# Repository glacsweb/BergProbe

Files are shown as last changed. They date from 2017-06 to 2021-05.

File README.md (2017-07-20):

# BergProbe
Repository for schematics and PCB layouts for the 2017 BergProbes.

### BergProbe/
Contains layouts for the BergProbe schematic (control+power board)

### BergProbe-Adapter/
Contains layouts for a breakout board for GPS and Radio modules, with connector for connecting to BergProbe board.

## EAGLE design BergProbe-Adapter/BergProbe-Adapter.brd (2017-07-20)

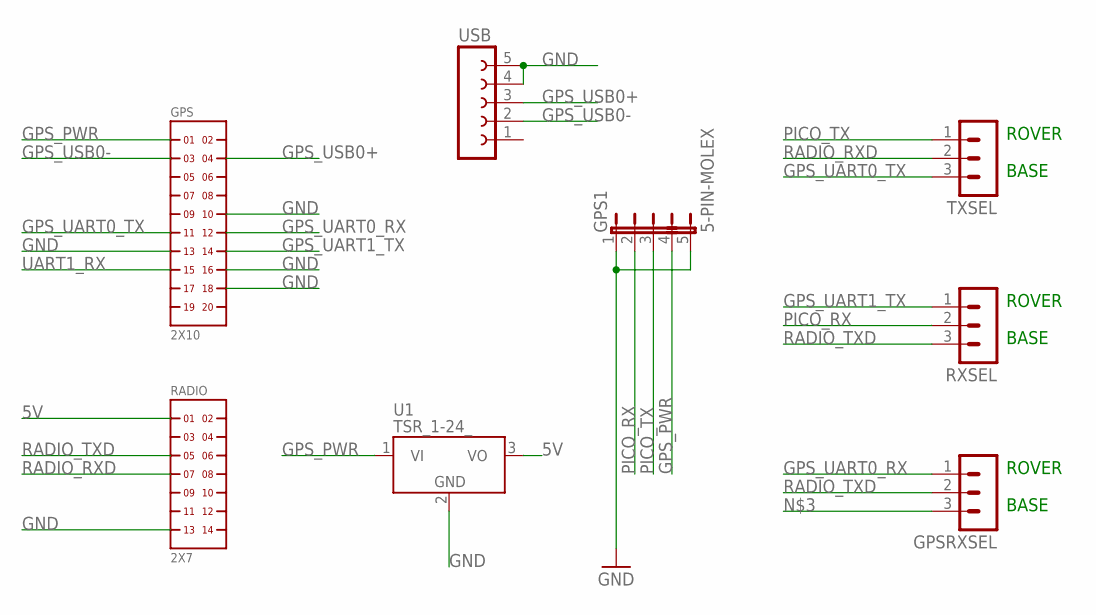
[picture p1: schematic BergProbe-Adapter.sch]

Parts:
GPS: 2X10
GPS1: 5-PIN-MOLEX; 5-MOLEX
GPSRXSEL: MA03-1
RADIO: 2X7
RXSEL: MA03-1
TXSEL: MA03-1
U1: TSR_1-24_; TSR-1
USB: FE05-1

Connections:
5V: RADIO.1, U1.3 (VO)
GND: GPS.10, GPS.13, GPS.16, GPS.18, GPS1.1, GPS1.5 (6), RADIO.13, U1.2 (GND), USB.4, USB.5
GPS_PWR: GPS.1, GPS1.4, U1.1 (VI)
GPS_UART0_RX: GPS.12, GPSRXSEL.1
GPS_UART0_TX: GPS.11, TXSEL.3
GPS_UART1_TX: GPS.14, RXSEL.1
GPS_USB0+: GPS.4, USB.3
GPS_USB0-: GPS.3, USB.2
PICO_RX: GPS1.2, RXSEL.2
PICO_TX: GPS1.3, TXSEL.1
RADIO_RXD: RADIO.7, TXSEL.2
RADIO_TXD: GPSRXSEL.2, RADIO.5, RXSEL.3
UART1_RX: GPS.15

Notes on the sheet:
ROVER
BASE

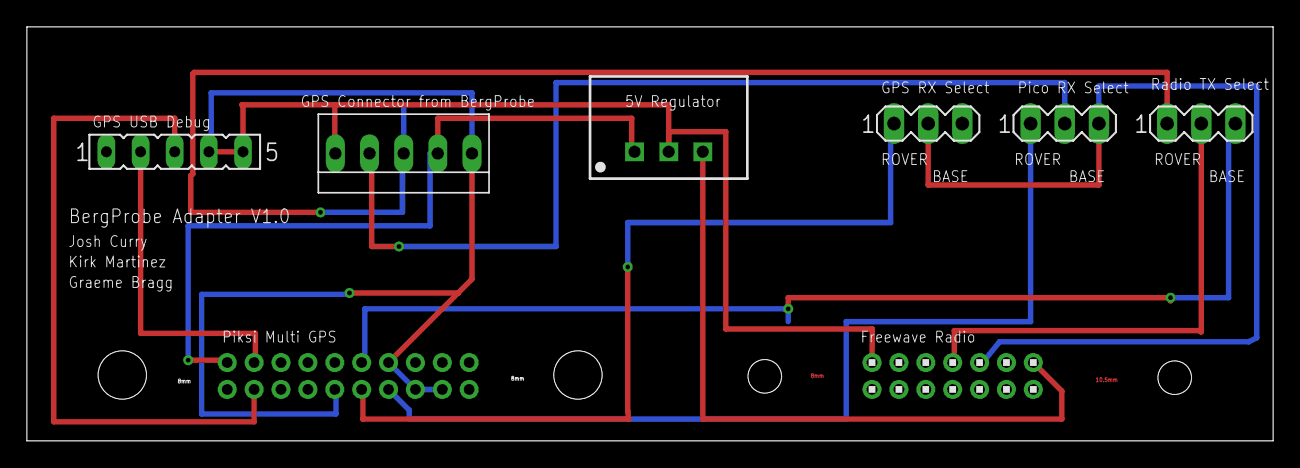
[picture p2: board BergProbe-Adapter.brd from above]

Board: 2 copper layers, 92.7 x 30.8 mm, 8 parts (1 on the bottom side), 12 nets.

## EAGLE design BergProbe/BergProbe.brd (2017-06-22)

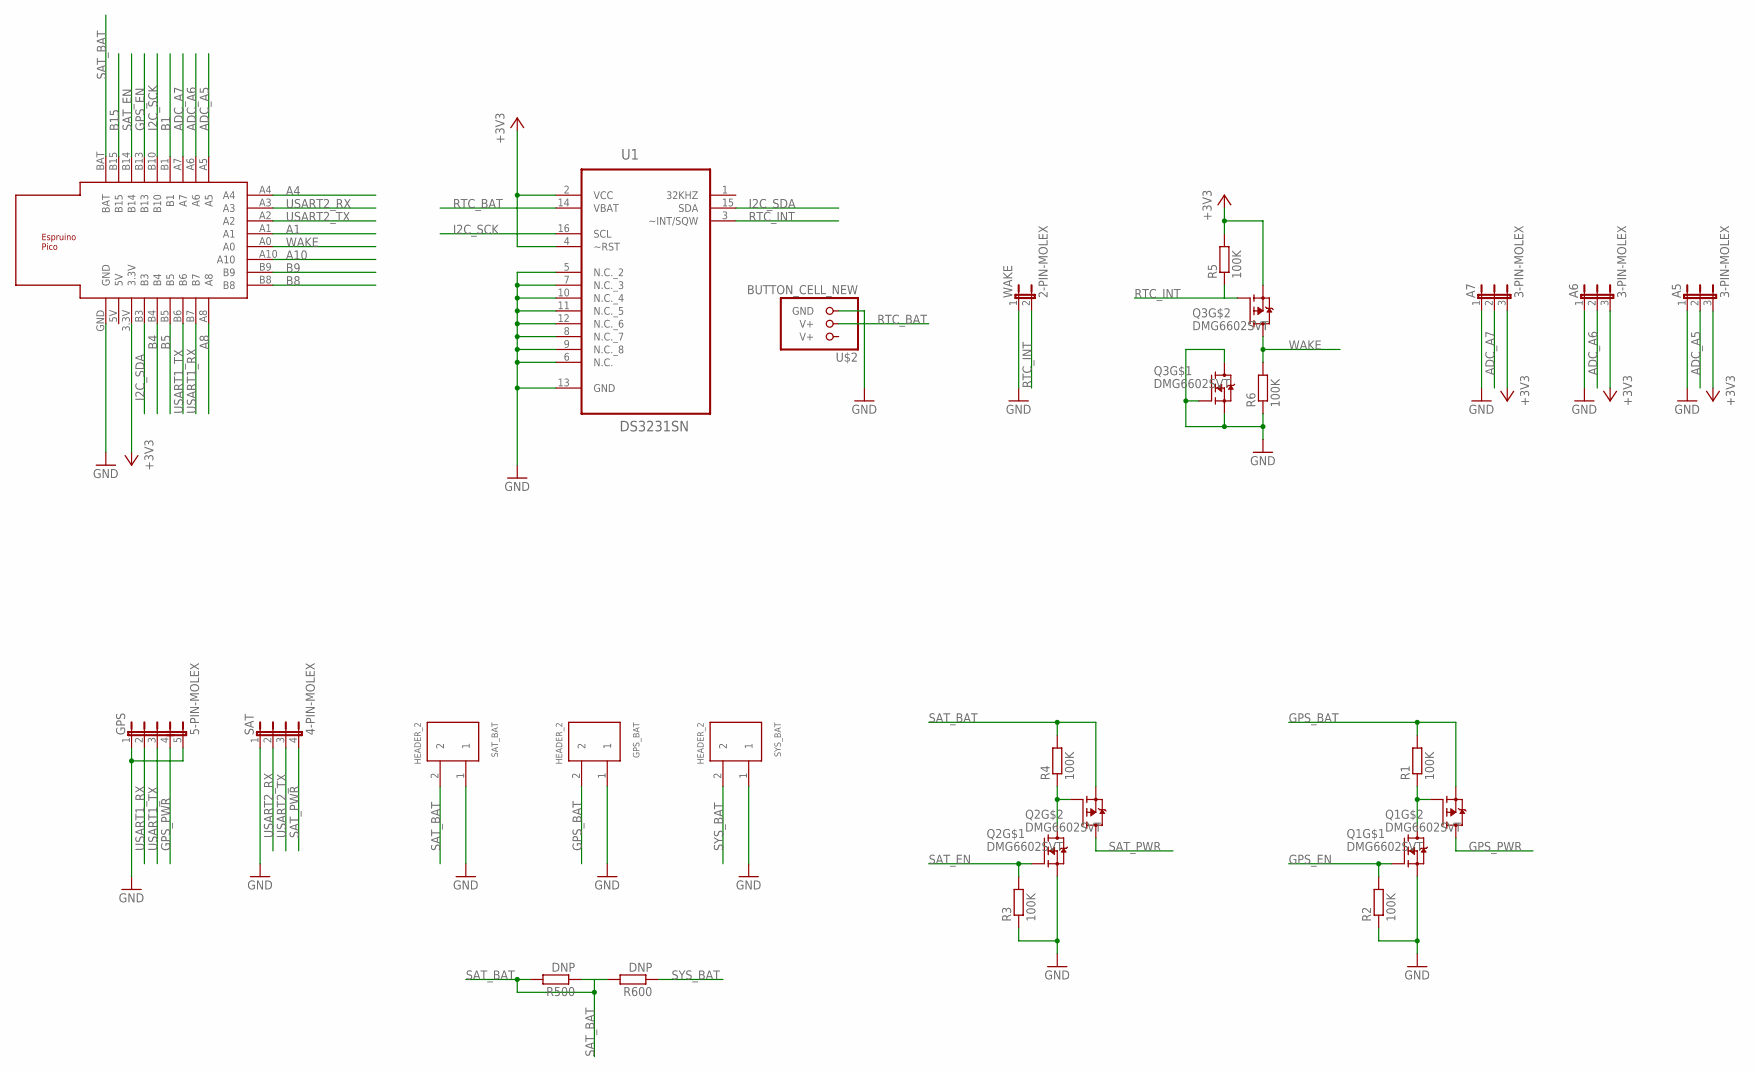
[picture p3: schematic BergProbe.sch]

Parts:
A5, A6, A7: 3-PIN-MOLEX; 3-MOLEX
GPS: 5-PIN-MOLEX; 5-MOLEX
GPS_BAT: HEADER_2; LUMBERG_CAGE_2
Q1, Q2, Q3: DMG6602SVT; TSOT26
R1, R2, R3, R4, R5, R6: 100K; R0805
R500, R600: DNP; R0805
SAT: 4-PIN-MOLEX; 4-MOLEX
SAT_BAT: HEADER_2; LUMBERG_CAGE_2
SYS_BAT: HEADER_2; LUMBERG_CAGE_2
U1: DS3231SN; SOIC127P1032X265-16N
U$1: ESPRUINO_PICO_SMDONLY
U$2: BUTTON_CELL_NEW; CR2016
WAKE: 2-PIN-MOLEX; 2-MOLEX

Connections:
+3V3: A5.3, A6.3, A7.3, Q3.P$2 (S), R5.2, U1.2 (VCC), U1.4 (~RST), U$1.3.3V
A1: U$1.A1
A4: U$1.A4
A8: U$1.A8
A10: U$1.A10
ADC_A5: A5.2, U$1.A5
ADC_A6: A6.2, U$1.A6
ADC_A7: A7.2, U$1.A7
B1: U$1.B1
B4: U$1.B4
B5: U$1.B5
B8: U$1.B8
B9: U$1.B9
B15: U$1.B15
GND: A5.1, A6.1, A7.1, GPS.1, GPS.5 (6), GPS_BAT.1, Q1.P$5 (S), Q2.P$5 (S), Q3.P$1 (G), Q3.P$5 (S), Q3.P$6 (D), R2.1, R3.1, R6.1, SAT.1, SAT_BAT.1, SYS_BAT.1, U1.5 (N.C._2), U1.6 (N.C.), U1.7 (N.C._3), U1.8 (N.C._7), U1.9 (N.C._8), U1.10 (N.C._4), U1.11 (N.C._5), U1.12 (N.C._6), U1.13 (GND), U$1.GND, U$2.GND, WAKE.1
GPS_BAT: GPS_BAT.2, Q1.P$2 (S), R1.2
GPS_EN: Q1.P$1 (G), R2.2, U$1.B13
GPS_PWR: GPS.4, Q1.P$4 (D)
I2C_SCK: U1.16 (SCL), U$1.B10
I2C_SDA: U1.15 (SDA), U$1.B3
unnamed: Q1.P$3 (G), Q1.P$6 (D), R1.1
unnamed: Q2.P$3 (G), Q2.P$6 (D), R4.1
RTC_BAT: U1.14 (VBAT), U$2.V+@2 (V+)
RTC_INT: Q3.P$3 (G), R5.1, U1.3 (~INT/SQW), WAKE.2
SAT_BAT: Q2.P$2 (S), R4.2, R500.1, R500.2, R600.2, SAT_BAT.2, U$1.BAT
SAT_EN: Q2.P$1 (G), R3.2, U$1.B14
SAT_PWR: Q2.P$4 (D), SAT.4
SYS_BAT: R600.1, SYS_BAT.2
USART1_RX: GPS.2, U$1.B7
USART1_TX: GPS.3, U$1.B6
USART2_RX: SAT.2, U$1.A3
USART2_TX: SAT.3, U$1.A2
WAKE: Q3.P$4 (D), R6.2, U$1.A0

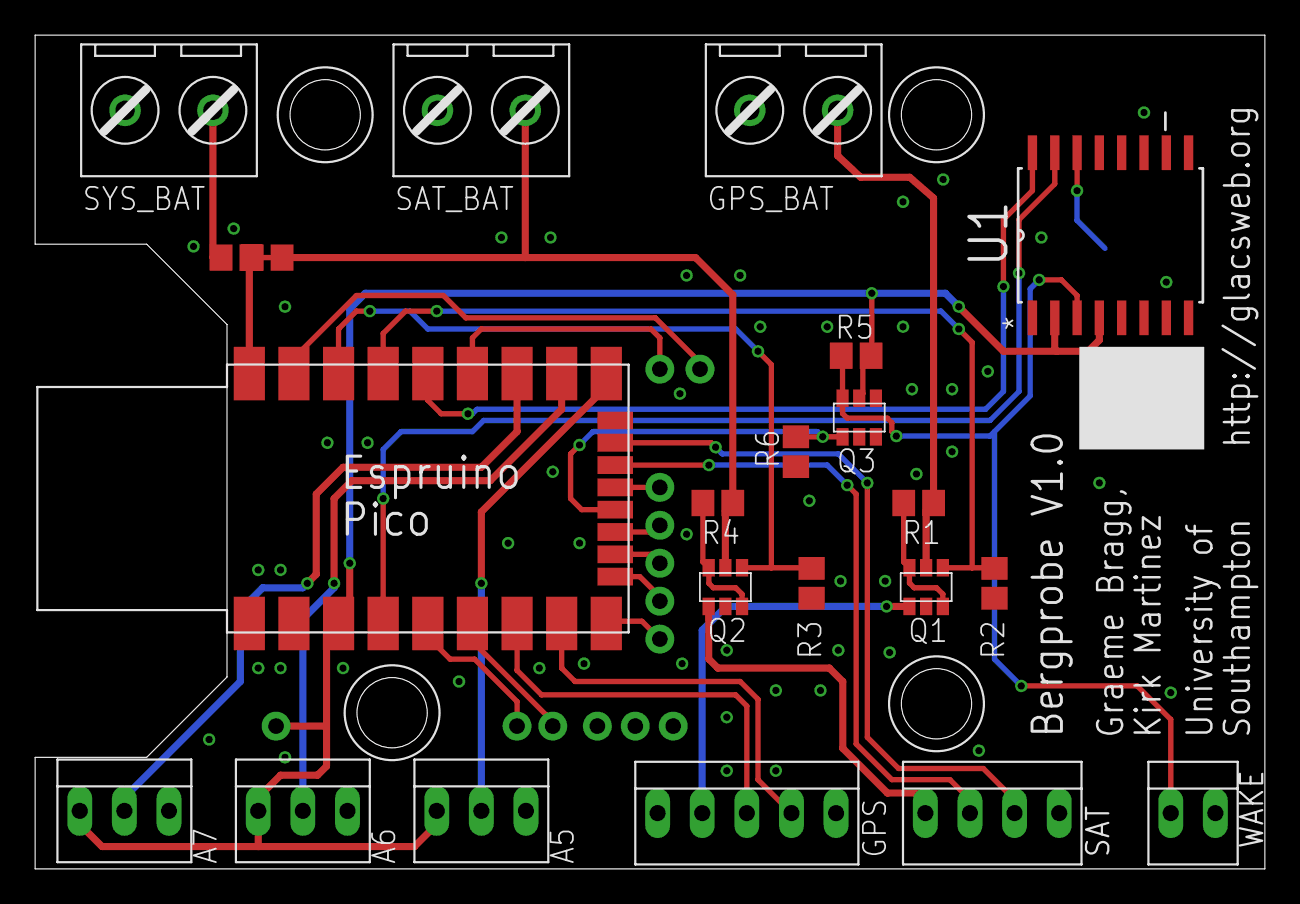
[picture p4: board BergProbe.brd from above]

Board: 2 copper layers, 70.0 x 47.5 mm, 23 parts (1 on the bottom side), 23 nets.

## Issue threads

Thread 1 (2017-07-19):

Pull ups on I2C missing

heliosfa, 2017-07-19:

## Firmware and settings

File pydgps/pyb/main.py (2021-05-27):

/* micropython ublox M9 based movement tracker
 * for the glacsweb.org project
 * Authors: Emily James 2020, University of Southampton

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
    see <https://www.gnu.org/licenses/> for the GNU General Public License
*/
from random import randint
from math import ceil
import pyb
import json
# from machine import WDT
from pyb import UART

import LCD
import Log
from Message import *
from Formats import *
import os

stat = None
pack_buf = []
nextpack = None
pl_length_rem = 0  # will be assigned when first packet found
until_len = None  # will be assigned when first packet found
calibrated = False

DEVICE_ID = 0
GPS_UART_PORT = 6
GPS_BAUDRATE = 38400
GPS_TIMEOUT = 1001 # ms
GPS_BUF_SIZ = 512 # bytes

IS_BASE_STATION = False
SVIN_DUR = 600 # 5 min
SVIN_ACC = 10000 # 10m
RADIO_UART_PORT = 3
RADIO_BAUDRATE = 38400
RADIO_TIMEOUT = 1000
RADIO_BUF_SIZ = 1024

# gpsIn = UART(6, 38400)
# gpsIn.init(38400, bits=8, parity=None, stop=1, read_buf_len=512,
#            timeout=1001)  # timeout should overlap epochs -> 1s atm

# wdt = WDT(timeout=10000)
TIME_CONF_LIMIT = 500  # number of readings before time-resync
timeConfidence = 0  # update time on 0 ==> on reset or start time is set

msg_buf = {}
msg_count = 0

monitoring = False

## MUST BE SET FROM 0 -> NO_MSGS ##
# determines location in each epoch list - don't change!
# LOC_CODE = 0
# STAT_CODE = 1
# SATINF_CODE = 2
# TIMEUTC_CODE = 3
# SVIN_CODE = 4
# set to -2 to disable (since -1 is used for no message, could cause accidental matches)
LOC_CODE = -2
STAT_CODE = -2
SATINF_CODE = -2
SVIN_CODE = -2
TIMEUTC_ENABLED = True

LOG_RAW = False
LOG_MEDIAN = True
LOG_BEST = True
UPDATE_DELAY = 1 # works best if harmonises with 1000ms i.e. 250, 500, 125, etc.

NO_READINGS = 25  # number of positions used in one reading
NO_MSGS = 3  # ROVER: number of messages per epoch (HPECEF, SAT, STATUS) = 3 --> NOTE that TIMUTC is used then discarded once time is updated
MAX_READING_ATTEMPTS = 100 # prevents livelock in case no message triples are valid
MAX_PACK_BUF = 25
CALIBRATION_TTL = 1000 # maximum number of bytes that will be read in one calibration before timeout
MAX_CALIBRATE_FAILURES = 50 # number of UART timeouts until calibration attepts stopped
# NO_MSGS = 5 # BASE STATION: number of messages per epoch (HPECEF, SAT, STATUS, TIMEUTC, SVIN) = 5
# MSG_PERIOD = 8 * 60 * 60  # (in seconds) every eight hours - min. 1 minute (50 readings taken with a delay of 1s
# between them)
MSG_PERIOD = 120  # two-minute debug mode
# MSG_PERIOD = 28800  # normal default
if MSG_PERIOD < 60:
    MSG_PERIOD = 60
# MSG_PERIOD *= 1000  # convert from s to ms

MSG_START_TIME = 12  # defines the first hour in which the readings will take place. no sub-hour accuracy as intended
                     # use is for < 10 readings per day
TRANSMIT_AFTER = 3 # 3 readings before transmit
MAX_TRANSMIT_ATTEMPTS = 3 # defines how many times a file will be transmitted before deletion

def loadBaseStationParams(data):
    global IS_BASE_STATION, SVIN_ACC, SVIN_DUR
    IS_BASE_STATION = True
    if 'svin_acc' in data:
        SVIN_ACC = data['svin_acc']
    if 'svin_dur' in data:
        SVIN_DUR = data['svin_dur']

def loadLogParams(data):
    global LOC_CODE, STAT_CODE, SATINF_CODE, TIMEUTC_ENABLED, SVIN_CODE, NO_MSGS, NO_READINGS, MAX_READING_ATTEMPTS, LOG_RAW, LOG_MEDIAN, LOG_BEST, MAX_PACK_BUF
    if 'no_readings' in data:
        NO_READINGS = data['no_readings']
    if 'max_reading_attempts' in data:
        MAX_READING_ATTEMPTS = data['max_reading_attempts']
    if 'max_pack_buf' in data:
        MAX_PACK_BUF = data['max_pack_buf']
    if 'log_raw' in data:
        LOG_RAW = data['log_raw']
    if 'log_median' in data:
        LOG_MEDIAN = data['log_median']
    if 'log_best' in data:
        LOG_BEST = data['log_best']
    if 'msgs_enabled' in data:
        msgs = data['msgs_enabled']
        c = 0
        for msg_type in msgs:
            if msgs[msg_type]:
                if msg_type == 'HPECEF':
                    LOC_CODE = c
                elif msg_type == 'STATUS':
                    STAT_CODE = c
                elif msg_type == 'SAT_INFO':
                    SATINF_CODE = c
                elif msg_type == 'TIMEUTC':
                    TIMEUTC_ENABLED = True
                    c -= 1
                elif msg_type == 'SVIN':
                    print("svin enabled")
                    SVIN_CODE = c
                    c -= 1
                c += 1
                print(LOC_CODE, STAT_CODE, SATINF_CODE, SVIN_CODE, c)
        if SVIN_CODE >= 0:
            SVIN_CODE = c

        NO_MSGS = c


def loadTimeParams(data):
    global MSG_PERIOD, MSG_START_TIME, TIME_CONF_LIMIT, UPDATE_DELAY, TRANSMIT_AFTER, MAX_TRANSMIT_ATTEMPTS
    if 'log_period_s' in data:
        MSG_PERIOD = data['log_period_s']
    if 'log_start' in data:
        MSG_START_TIME = data['log_start']
    if 'update_rtc_time' in data:
        TIME_CONF_LIMIT = data['update_rtc_time']
    if 'update_delay' in data:
        UPDATE_DELAY = data['update_delay']
    if 'transmit_after' in data:
        TRANSMIT_AFTER = data['transmit_after']
    if 'transmit_attempts' in data:
        MAX_TRANSMIT_ATTEMPTS = data['transmit_attempts']

def loadUARTParams(data):
    global GPS_UART_PORT, GPS_BAUDRATE, GPS_TIMEOUT, CALIBRATION_TTL, GPS_BUF_SIZ, gpsIn, DEVICE_ID, \
        MAX_CALIBRATE_FAILURES, RADIO_UART_PORT, RADIO_BAUDRATE, RADIO_TIMEOUT, RADIO_BUF_SIZ
    if 'device_id' in data:
        DEVICE_ID = data['device_id']
    if 'gps_uart' in data:
        GPS_UART_PORT = data['gps_uart']
    if 'gps_baudrate' in data:
        GPS_BAUDRATE = data['gps_baudrate']
    if 'gps_timeout' in data:
        GPS_TIMEOUT = data['gps_timeout']
    if 'gps_buffer_size' in data:
        GPS_BUF_SIZ = data['gps_buffer_size']
    if 'calibration_ttl' in data:
        CALIBRATION_TTL = data['calibration_ttl']
    if 'max_calibration_fail' in data:
        CALIBRATION_TTL = data['max_calibration_fail']
    if 'radio_uart' in data:
        RADIO_UART_PORT = data['radio_uart']
    if 'radio_baudrate' in data:
        RADIO_BAUDRATE = data['radio_baudrate']
    if 'radio_timeout' in data:
        RADIO_TIMEOUT = data['radio_timeout']
    if 'radio_buffer_size' in data:
        RADIO_BUF_SIZ = data['radio_buffer_size']

def getParamsFromConfig():
    try:
        with open("config.json") as f:
            data = json.load(f)
        # print(data)
        baseStation = 'base_station' in data and data['base_station']
        if baseStation:
            loadBaseStationParams(data)
        if 'lcd_start_on' in data and data['lcd_start_on']:
            LCD.powered = 1
        else:
            LCD.powered = 0

        loadLogParams(data)
        loadTimeParams(data)
        loadUARTParams(data)
    except Exception as e:
        print("Error {0}, using default parameters".format(e))


def calibrate():
    global CALIBRATION_TTL
    print("Calibrating...", end=" ")
    start_bit_one = False
    start_bit_two = False
    ttl = CALIBRATION_TTL
    remaining_failures = MAX_CALIBRATE_FAILURES
    while not (start_bit_one and start_bit_two) and ttl > 0 and remaining_failures > 0:
        curr = gpsIn.read(1)
        ttl -= 1
        if curr == b'\xb5':
            start_bit_one = True
        elif curr == b'\x62':
            start_bit_two = True
        elif curr is None:
            # uart timeout
            remaining_failures -= 1
        else:
            start_bit_one = False
            start_bit_two = False

    if ttl > 0 and remaining_failures > 0:
        print("Calibration Finished")
    else:
        print("Calibration timed out")
    return ttl > 0 and remaining_failures > 0

def readBytes():
    global nextpack, pack_buf, calibrated, gpsIn
    if gpsIn is None or len(pack_buf) > MAX_PACK_BUF:
        return False
    print("Reading...", end="")
    calibrated = gpsIn.read(2) == b'\xb5\x62'
    if not calibrated:
        calibrated = calibrate()
        Log.CalibrateEvent().writeLog()
    if not calibrated:
        Log.CalibrationTimeoutEvent().writeLog()
        return False
    # print(calibrated)
    nextpack = bytearray(b'\xb5\x62')
    class_id = gpsIn.read(2)
    pack_len_bytes = gpsIn.read(2)
    pack_len = U2(pack_len_bytes)
    # print(pack_len_bytes,pack_len, "bytes long")

    if pack_len > 100 and class_id != bytearray(b'\x01\x35'):
        Log.UnacceptableLengthError(pack_len_bytes).writeLog()
        print(class_id)
        print("BAD LENGTH", pack_len)
        return False
    elif class_id == bytearray(b'\x01\x35'):
        print("Sat message, length capped...", end="")
        Log.LengthForceError(b'\x01', b'\x35', pack_len_bytes, u2toBytes(8)).writeLog()
        pack_len = 8
        pack_len_bytes = u2toBytes(pack_len)
    payload = gpsIn.read(pack_len)
    crc = gpsIn.read(2)
    if crc is None:
        crc = b'\x00\x00'
    # print(crc,"crc")
    try:
        nextpack.extend(class_id)  # append class and ID to byte
        nextpack.extend(pack_len_bytes)
        nextpack.extend(payload)
        nextpack.extend(crc)
        pack_buf.append(nextpack)
    except Exception as e:
        Log.UnknownError("Reading bytes from UART").writeLog()
        print(e)
        print("Error:")
        print(class_id)
        print(pack_len_bytes)
        print(payload)
        print(crc)
        print("End error")
        # log error?
        return False
    nextpack = None
    print("Finished.")
    return True


# 0 -> High-precision ECEF data
# 1 -> GPS Status (ttff, fix status, etc.)
# 2 -> Satellite information (notably the number of satellites used)
# 3 -> Survey-in data (base station)
def getMessageFromBuffer():
    global pack_buf, msg_buf, LOC_CODE, STAT_CODE, SATINF_CODE, NO_MSGS, TIMEUTC_ENABLED, fixOK, dgpsUsed
    if len(pack_buf) == 0:
        return None, -1
    print(len(pack_buf))
    byte_stream = pack_buf[0]
    del pack_buf[0]
    print(byte_stream)
    msg = None
    try:
        msg = binaryParseUBXMessage(byte_stream)
    except:
        Log.UnknownError("when parsing ubx message from bytestream")

    if msg is None:
        return None, -1

    tow = msg.getTOW()
    # print(len(msg_buf), "messages in buffer")
    if tow not in msg_buf:
        msg_buf[tow] = [None] * NO_MSGS
    code = -1
    if isinstance(msg, HPECEF) and LOC_CODE >= 0:
        code = LOC_CODE
    elif isinstance(msg, Status) and STAT_CODE >= 0:
        code = STAT_CODE
        fixOK = msg.gpsFixOK
        dgpsUsed = msg.diffSol
    elif isinstance(msg, SatInfo) and SATINF_CODE >= 0:
        code = SATINF_CODE
    elif isinstance(msg, TimeUTC) and TIMEUTC_ENABLED:
        updateTime(msg)
    # SVIN should only come in on base station, leaving code here for ease of copying, could also make code more
    # deployable by copying gps-read code?
    elif isinstance(msg, SVIN) and SVIN_CODE >= 0:
        return msg, SVIN_CODE
    else:
        code = -1

    if code != -1:  # just in case msg is not being used -> TIMEUTC? maybe another message has been enabled by accident i.e. LLH
        msg_buf[tow][code] = msg
    updateLEDs()  # update LEDs as readings taken - shows if fix dies during read
    return msg, code


reading = False

# tells us if the last epoch was corrupted by:
# - not enough messages read from gps
# - some messages invalid from last epoch
def invalidEpoch(epoch_msgs):
    global NO_MSGS, STAT_CODE, LOC_CODE
    return any(map(lambda r: r is None, epoch_msgs)) or len(epoch_msgs) < NO_MSGS or not epoch_msgs[
        STAT_CODE].gpsFixOK or epoch_msgs[LOC_CODE].invalidFix


def getReadings(i=0):
    global msg_buf, msg_count, NO_READINGS, STAT_CODE, timeConfidence, MSG_PERIOD, reading, fixOK, dgpsUsed
    # shoudln't read twice at same time, or if nothing to log don't bother
    if reading or not (LOG_RAW or LOG_BEST or LOG_MEDIAN):
        print("Duplicate call?")
        return
    LCD.reading = True
    reading = True
    LCD.makeLCDBusy("getReadings")
    msg_buf = {}
    curepoch = 0
    lastepoch = 0
    chosen_msgs = []
    ttl = MAX_READING_ATTEMPTS # time to live, prevents livelock
    epochs = 0
    while epochs < (NO_READINGS + 1) and ttl > 0:
        bytesavailable = readBytes()
        print(epochs)
        if not bytesavailable:
            ttl -= 1
            # add delay to try to dislodge timeout / get more data in buffer
            pyb.delay(100)
            continue # restart iteration with hopefully more bytes in buffer - ttl should stop if many attempts taken
        msg, id = getMessageFromBuffer()
        print(msg, id)
        if msg is None:
            pyb.delay(10)
            continue
        curepoch = msg.getTOW()

        if curepoch != lastepoch and lastepoch != 0:
            print("------ ### ------")
            # if any messages are missing from last epoch, delete data from that epoch as unreliable (incomplete metadata)
            lastepoch_msgs = msg_buf[lastepoch]
            if invalidEpoch(lastepoch_msgs):
                msg_count -= sum(map(lambda r: r is not None, lastepoch_msgs))
                print("Some messages none on turn of next epoch, deleting epoch...")
                print(lastepoch_msgs)
                del msg_buf[lastepoch]
                ttl -= 1
                lastepoch = curepoch # might not work? needs testing
                continue # skip count increment
            elif LOG_RAW:
                # safe to log as raw data
                Log.ECEFLog(lastepoch_msgs[LOC_CODE], b'\xF1', lastepoch_msgs[SATINF_CODE]).writeLog()
                Log.LocationEvent(b'\x11').writeLog()  # write event log for location write
            epochs += 1
        # print(msg, id, msg_count)
        lastepoch = curepoch
        # original code for detecting location invalid -> moved to last epoch calculation
        # invalidFix = id == STAT_CODE and not msg.gpsFixOK or id == LOC_CODE and msg.invalidFix
        # if invalidFix:
        #     msg_count -= id
        #     del msg_buf[msg.iTOW]
        #     print("Invalid fix, deleting msg", msg_buf, msg_count, id == STAT_CODE and not msg.gpsFixOK, id == LOC_CODE and msg.invalidFix)
        #     Log.UnknownError("Invalid location deleted from buffer").writeLog()
        # else:

    # 0 msgs will only happen if timeout
    if len(msg_buf) > 0:
        del msg_buf[curepoch] # trim last epoch from buffer
    timeConfidence -= 1

    # clock will drift as time continues, update time when this reaches 0 (see TIME_CONF_LIMIT for readings before
    # reset)
    if LOG_MEDIAN and len(msg_buf) > 0:
        # print(msg_buf, msg_count)
        type_code = b'\x12'
        chosen_msgs.append((type_code, getMedianMsg(msg_buf)))

    if LOG_BEST and len(msg_buf) > 0:
        # take message with smallest pAcc --> most accurate of the readings
        type_code = b'\x13'
        chosen_msgs.append((type_code, getBestAcc(msg_buf)))

    if len(chosen_msgs) > 0:
        print(chosen_msgs)
        for t, m in chosen_msgs:
            # print(t, m)
            location = m[LOC_CODE]
            sats = m[SATINF_CODE]
            Log.ECEFLog(location, t, sats).writeLog()
            Log.LocationEvent(t).writeLog() # write event log for location write

    if not IS_BASE_STATION:
        transmitLogs()

    updateLCD()
    msg_buf = {}
    msg_count = 0
    LCD.makeLCDFree()
    reading = False
    LCD.reading = False
    print("\nREADINGS DONE\n")
    if LCD.powered == 0:
        pyb.stop() # put board into low-power mode until ext. interrupt

def forceReading():
    global clock
    print("\n\nForcing reading\n\n")
    clock.wakeup(None)
    getReadings()
    if not IS_BASE_STATION:
        clock.wakeup(10000, initialTimer)


def updateTime(timeMsg):
    global clock, timeConfidence, TIME_CONF_LIMIT
    if type(timeMsg) is not TimeUTC or not timeMsg.validTime() or timeConfidence > 0:
        print("No clock update: ", timeConfidence)
        timeConfidence -= 1
        return
    print("!!! Updating clock !!!")
    LCD.makeLCDBusy("Time update")
    Log.TimeUpdateEvent().writeLog()
    timeConfidence = TIME_CONF_LIMIT
    # assume Monday as gps doesn't give this data hence weekday=0
    LCD.makeLCDFree()
    clock.datetime((timeMsg.getYear(), timeMsg.getMonth(), timeMsg.getDay(), 1,
                    timeMsg.getHour(), timeMsg.getMinute(), timeMsg.getSeconds(), timeMsg.getNano()))


t_attempts = 1
# 300 readings - for loop?
# long timeout - .5s to keep in 1s epoch?
#

# RTC.wakeup(timeout, callback)
# can be used to do frequent events (callback might be typed badly idk)
# means we can wakeup from pyb.stop() (500uA) and immediately call a few iterations of main()

# allow for further implementation of LR comms - UART?
def transmitLogs():
    global TRANSMIT_AFTER, MAX_TRANSMIT_ATTEMPTS, t_attempts, dgpsUsed
    # don't run if don't want to transmit for some reason
    print("Might be transmitting..?",str(t_attempts),dgpsUsed)
    LCD.makeLCDBusy("transmitLogs")
    # don't transmit if configured not to (base station?) or if there is no radio connection
    if MAX_TRANSMIT_ATTEMPTS <= 0 or not dgpsUsed:
        return
    elif t_attempts >= TRANSMIT_AFTER:
        try:
            print(Log.waiting_logs)
            for file in Log.waiting_logs:
                print(file)
                with open(file, "rb") as f:
                    data = f.read(50)
                    while data != b'':
                        radio.write(data)
                        data = f.read(50)
                Log.waiting_logs[file] += 1
                if Log.waiting_logs[file] >= MAX_TRANSMIT_ATTEMPTS:
                    os.remove(file)
                    del Log.waiting_logs[file]
                    Log.LocationEvent(b'\x1F').writeLog()
            Log.LocationEvent(b'\x1E').writeLog()
        except Exception as e:
            print("Error while transmitting", e)
            Log.UnknownError("Transmit error "+str(e)).writeLog()
        t_attempts = 1
    else:
        t_attempts += 1

    LCD.makeLCDFree()
    # original intent was to transmit once per day, so could accumulate value
    # based on period and number of logs taken
    # implementation could be abstracted to UART or SPI output -> currently no plan to use real satellite link


def updateLCD():
    global UPDATE_DELAY
    Log.LCDEvent(b'\x20').writeLog()
    LCD.updateLCD(UPDATE_DELAY)


dgpsUsed = False
fixOK = False
# might be useful for visual status - green on fix etc.
def updateLEDs():
    global fixOK, dgpsUsed
    if fixOK:
        pyb.LED(2).on()
        pyb.LED(1).off()
    else:
        pyb.LED(2).off()
        pyb.LED(1).on()

    if dgpsUsed:
        pyb.LED(4).on()
    else:
        pyb.LED(4).off()

# while True:
#     msg = getMessage()
#     updateTime(msg)
#     getLocation(msg)
#     logLocation(msg)
#     transmitLocation(msg)
#     updateLCD()

def getAcc(msgSet):
    global LOC_CODE
    return msgSet[LOC_CODE].getPAcc()


def getEuclidiean(msgTriple):
    global LOC_CODE
    msg = msgTriple[1][LOC_CODE]
    px, py, pz = msg.get3DPos()
    return px ** 2 + py ** 2 + pz ** 2


# SHOULD return a list of messages with indexes matching the codes
def getMedianMsg(msgs):
    sorted_msg_values = list({key: value for key, value in
                         sorted(msgs.items(), key=lambda item: getEuclidiean(item))})
    halfway_point = (len(sorted_msg_values) + 1) / 2 - 1
    # easier to choose left value rather than average between the two
    med = msgs[sorted_msg_values[int(ceil(halfway_point))]]
    return med


def getBestAcc(msgs):
    msgs = sorted(msgs.values(), key=getAcc)
    return msgs[0]


surveying = False
def startSVIN(dur=600, acc=1000):
    global surveying
    bs = bytearray()
    bs.append(0xb5)
    bs.append(0x62)
    bs.append(0x06)
    bs.append(0x71)
    bs.append(0x28)
    bs.append(0)

    bs.append(0)
    bs.append(0)
    bs.append(1)
    bs.append(0)

    for i in range(20):
        bs.append(0)
    # bs.append(0x58)
    # bs.append(0x02)
    # bs.append(0)
    # bs.append(0)

    bs.extend(u4toBytes(dur))
    bs.extend(u4toBytes(acc))

    # bs.append(0xe8)
    # bs.append(0x03)
    # bs.append(0)
    # bs.append(0)
    for i in range(8):
        bs.append(0)

    ck_a, ck_b = ubxChecksum(bs[2:])
    bs.append(ck_a)
    bs.append(ck_b)
    gpsIn.write(bs)
    return bs

def stopSVIN(svinmsg):
    bs = bytearray()
    bs.append(0xb5)
    bs.append(0x62)
    bs.append(0x06)
    bs.append(0x71)
    bs.append(0x28)
    bs.append(0)

    bs.append(0)
    bs.append(0)
    bs.append(2)
    bs.append(0)

    bs.extend(svinmsg.meanX[0])
    bs.extend(svinmsg.meanY[0])
    bs.extend(svinmsg.meanZ[0])

    bs.extend(svinmsg.meanXHp[0])
    bs.extend(svinmsg.meanYHp[0])
    bs.extend(svinmsg.meanZHp[0])

    bs.append(0)
    bs.extend(svinmsg.meanAcc[0])

    bs.append(0)
    bs.append(0)
    bs.append(0)
    bs.append(0)

    bs.append(0)
    bs.append(0)
    bs.append(0)
    bs.append(0)
    for i in range(8):
        bs.append(0)

    ck_a, ck_b = ubxChecksum(bs[2:])
    bs.append(ck_a)
    bs.append(ck_b)
    gpsIn.write(bs)
    return bs

def saveCFG():
    bs = bytearray()
    bs.append(0xb5)
    bs.append(0x62)
    bs.append(0x06)
    bs.append(0x09)
    bs.extend(u2toBytes(13))

    bs.extend(x4toBytes(0))
    bs.extend(x4toBytes(7967))
    bs.extend(x4toBytes(0))
    bs.extend(x1toBytes(2))

    ck_a, ck_b = ubxChecksum(bs[2:])
    bs.append(ck_a)
    bs.append(ck_b)
    gpsIn.write(bs)
    return bs

def searchForSVIN():
    global SVIN_CODE
    code=-1
    while code != SVIN_CODE:
        pyb.delay(200)
        readBytes()
        msg, code = getMessageFromBuffer()
    return msg

cursvin=None
def toggleSVIN():
    global surveying, cursvin
    surveying = not surveying
    LCD.surveying = not LCD.surveying
    LCD.forceUpdateLCD()
    if surveying:
        print("Starting survey")
        startSVIN(SVIN_DUR, SVIN_ACC)
    elif not surveying and cursvin is not None:
        print("Stopping survey")
        stopSVIN(cursvin)
    saveCFG()
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

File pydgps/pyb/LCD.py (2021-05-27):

/* micropython ublox M9 based movement tracker
 * for the glacsweb.org project
 * Authors: Emily James 2020, University of Southampton

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
    see <https://www.gnu.org/licenses/> for the GNU General Public License
*/
import pyb
from lcd160cr import *
from Formats import *

lcd = None


def rgb(r, g, b):
    return LCD160CR.rgb(r, g, b)

def resetPen():
    lcd.set_pos(0, 0)
    lcd.set_font(1, 0)
    lcd.set_scroll(False)
    lcd.set_text_color(lcd.rgb(255, 255, 255), lcd.rgb(0, 0, 0))
    lcd.set_pen(rgb(255, 255, 255), rgb(0, 0, 0))


def initLCD():
    global lcd
    lcd = LCD160CR('X')
    lcd.set_orient(LANDSCAPE_UPSIDEDOWN)
    lcd.set_pen(lcd.rgb(255, 255, 255), lcd.rgb(0, 0, 0))
    lcd.erase()
    resetPen()
    # lcd.save_to_flash()
    # lcd.write("LCD initiated")
    # for i in range(0, 20):
    #     lcd.write(str(i) + "\n")
    return lcd


def writeToScreen(text):
    lcd.write(text)


def writeLine(text):
    lcd.write(text + "\n\r")


def clearScreen():
    lcd.erase()


def changeTextColour(fg, bg=rgb(0, 0, 0)):
    lcd.set_text_color(fg, bg)
    return fg, bg


def changeTextColourRGBNoBG(r, g, b):
    return changeTextColour(rgb(r, g, b), rgb(0, 0, 0))


def changePenColour(line, fill=rgb(0, 0, 0)):
    lcd.set_pen(line, fill)
    return line, fill


def resetPenPos():
    lcd.set_pos(0, 0)


def initLCDAPI(log_freq=0, log_start=0, keep_raw=False, keep_med=False, keep_best=False, baseStation=True, svin_dur=0,
               svin_acc=0, svintoggle=lambda: print(), readCallback=lambda: print()):
    global pages, powered, lcd, svinpage, locpage, forceRead
    forceRead = readCallback
    initLCD()
    # lcd.save_to_flash()
    setupPowerButton()
    pages.append(getSettingsScreen(log_freq, log_start, keep_raw, keep_med, keep_best))
    if baseStation:
        print(baseStation, "==> added")
        pages.append(getSVINSettingsScreen(svin_dur, svin_acc, svintoggle))
        svinpage = len(pages)
        pages.append(getSVINMonitorScreen())

    locpage = len(pages)
    pages.append(getLocMonitorScreen(forceRead))
    checkPower()


pages = []
page = 0
powered = 0
UPDATE_TIME = 1000  # minimum ms before LCD updates on-screen info - is affected by gps timeout
updateIn = 0  # force update on startup


def updateLCD(delay):
    global pages, page, updateIn, UPDATE_TIME, reading
    page_ = pages[page]
    checkPower()
    print("checking lcd update:", page, powered, reading, updateIn)
    if powered == 0 or reading:
        return
    elif updateIn <= 0:
        updateIn = UPDATE_TIME
        resetPen()
        page_.eraseScreen()
        page_.drawWidgets()
    else:
        updateIn -= delay

    touches = page_.getTouches()
    if len(touches) > 0:
        touches[0].callback()


def forceUpdateLCD():
    global updateIn, pages, page
    updateIn = 0 # force update immediately after draw
    page_ = pages[page]
    checkPower()
    if powered == 0 or reading:
        return
    resetPen()
    page_.eraseScreen()
    page_.drawWidgets()


def setupPowerButton():
    b = pyb.Switch()
    b.callback(togglePower)


powerchange = True
def togglePower():
    global powered, powerchange
    print("--------")
    print("POWER UPDATE")
    print(powered, powerchange)
    powered = 1 - powered
    lcd.set_power(powered)
    powerchange = True
    print(powered, powerchange)
    print("--------")

def powerOn():
    global powered, powerchange
    powered = 1
    lcd.set_power(powered)
    powerchange = True

def powerOff():
    global powered, powerchange
    powered = 0
    lcd.set_power(powered)
    powerchange = True

def checkPower():
    global powered, powerchange
    if not powerchange:
        return

    # lcd.set_power(powered)
    if powered == 1:
        lcd.set_orient(LANDSCAPE_UPSIDEDOWN)
        # draw busy page if started during busy period
        if reading:
            makeLCDBusy("getReadings")
        Log.LCDEvent(b'\x20').writeLog()
    else:
        Log.LCDEvent(b'\x21').writeLog()
        # pyb.stop()
    powerchange = False


def drawPage():
    global powered, pages, page
    if powered == 1:
        resetPen()
        pages[page].drawWidgets()


def forceDrawPage(page):
    if powered == 1:
        resetPen()
        clearScreen()
        page.drawWidgets()


def leftPage():
    global pages, page, powered
    print("Changing page - L")
    if len(pages) == 0 or powered == 0:
        print("No pages or unpowered:", len(pages), powered)
        return
    page -= 1
    if page < 0:
        page = len(pages) - 1
    forceUpdateLCD()


def rightPage():
    global pages, page, powered
    print("Changing page - R")
    if len(pages) == 0 or powered == 0:
        print("No pages or unpowered:", len(pages), powered)
        return
    page += 1
    if page >= len(pages):
        page = 0
    forceUpdateLCD()


lbutton, rbutton = (None, None)


def getLRButtons():
    global lbutton, rbutton
    if lbutton is not None and rbutton is not None:
        return lbutton, rbutton

    ltriangle, rtriangle = getLRTriangles()
    rbutton = RectButton(llims=(135, 5), ulims=(155, 25), outlineColour=rgb(48, 48, 48),
                         fillColour=rgb(199, 199, 199),
                         filled=True, detail=[rtriangle], callback=rightPage)
    lbutton = RectButton(llims=(135, 103), ulims=(155, 123), outlineColour=rgb(48, 48, 48),
                         fillColour=rgb(199, 199, 199),
                         filled=True, detail=[ltriangle], callback=leftPage)
    return lbutton, rbutton


def getBusyScreen(operation):
    global lcd
    title = TextLine("WARNING", 19, 10, size=0, font=3)
    line1 = TextLine("Operation", 19, 30, size=0, font=3)
    line2 = TextLine("in", 19, 50, size=0, font=3)
    line3 = TextLine("progress", 19, 70, size=0, font=3)
    operation = TextLine("("+operation+")", 19, 90, size=0, font=3)
    busyscreen = Screen(lcd, widgets=[title, line1, line2, line3, operation])
    return busyscreen


reading = False


def makeLCDBusy(operation="unknown"):
    global reading
    operation = "unknown" if operation is None else operation
    Log.LCDEvent(b'\x22').writeLog()
    reading = True
    forceDrawPage(getBusyScreen(operation))


def makeLCDFree():
    global reading
    Log.LCDEvent(b'\x23').writeLog()
    reading = False
    forceUpdateLCD()


def getLRTriangles():
    rtriangle = bytearray()
    rtriangle.extend(bytes([141, 19]))
    rtriangle.extend(bytes([145, 11]))
    rtriangle.extend(bytes([149, 19]))
    rtriangle.extend(bytes([141, 19]))

    ltriangle = bytearray()
    ltriangle.extend(bytes([141, 109]))
    ltriangle.extend(bytes([145, 117]))
    ltriangle.extend(bytes([149, 109]))
    ltriangle.extend(bytes([141, 109]))
    return ltriangle, rtriangle


def checkTouches():
    global pages, page
    if powered == 1:
        touches = pages[page].getTouches()
        if len(touches) > 0:
            touch = touches[0]
            touch.callback()
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

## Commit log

2017-06-14 Initial commit with base schematic
    [BergProbe.sch]
2017-06-14 Initial (incomplete) PCB Layout.
    [BergProbe.brd, BergProbe.sch]
2017-06-17 Progress on PCB layout. Added analogue headers to schematic.
    [BergProbe.brd, BergProbe.sch]
2017-06-18 PCB Layout complete EXCEPT for wakeup switch/RTC Alarm finalisation.
    [BergProbe.brd, BergProbe.sch]
2017-06-22 FInal PCB and schematic version
    [BergProbe.brd, BergProbe.sch]
2017-06-22 brd tweak
    [BergProbe.brd]
2017-06-22 Gerber files added
    [BergProbe.GBL, BergProbe.GBO, BergProbe.GBP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]
2017-07-20 Moved files into directory structure
    [BergProbe.GBL, BergProbe.GBO, BergProbe.GBP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]
2017-07-20 Added BergProbe-Adapter Schematic and PCB for review.
    [BergProbe-Adapter.brd, BergProbe-Adapter.sch]
2017-07-20 Added mounting holes. Will need checking; only done roughly with callipers.
    [BergProbe-Adapter.brd]
2017-07-20 Modified hole placings. Also moved tracks away from holes just in case.
    [BergProbe-Adapter.brd]
2017-07-20 Changed text layer so not on copper.
    [BergProbe-Adapter.brd]
2017-07-21 Oops removed small track stubs
    [BergProbe-Adapter.brd]

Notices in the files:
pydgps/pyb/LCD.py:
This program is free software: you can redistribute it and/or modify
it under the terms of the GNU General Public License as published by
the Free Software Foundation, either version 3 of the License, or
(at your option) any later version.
